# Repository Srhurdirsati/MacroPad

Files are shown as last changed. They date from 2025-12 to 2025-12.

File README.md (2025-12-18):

# MacroPad
This is a small **4-key RGB macro pad** project built using the Seeed Studio XIAO RP2040.  
It is designed as a beginner-friendly hardware + firmware project and can be used as a USB macro pad for shortcuts, media control, or productivity.

---

##  Features

- 4 mechanical keys
- Per-key RGB lighting using SK6812 MINI LEDs
- Rotary encoder for volume / Brightness
- OLED display for status 
- USB HID 
- Compact custom PCB
- Customizable Code For Customized Features

---

## Components Used

### Microcontroller
- **Seeed Studio XIAO RP2040**  
  Link: https://robu.in/product/seeed-studio-xiao-rp2040-v1-0/ $6 With Shipping

### Mechanical Switches
- **Cherry MX 5-pin switches (Silent Red)**  
  Link:  
  https://www.thecosmicbyte.com/product/cherry-mx-mechancial-5-pin-switches-compatible-with-hot-swappable-keyboards-pack-of-10/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 $6 With Shipping 

### Other Parts
- SK6812 RGB LEDs (5 pcs) $1 From My Local Shop 
- Rotary encoder wih switch  $2 from my local shop 
- [0.96" I2C OLED display](https://robu.in/product/0-96-oled-display-module/) - $3 with shipping  
- Custom PCB (JLCPCB – approx **$11 USD** for prototype with shiping )

   GRAND TOTAL = 6+6+1+2+3+11 = 39 => ~$40

---

## How To Use Rorary Encoder 

- Double Click to switch btw brightness and volume
- Scroll to adjust
- Tripple Click To Switch RGB Modes
- Single Click For Play Pause

   CODE CAN BE EDITED AS PER CHOICE   

---

## Images

Schematic

PCB

3D



Top

Top 2

Assembly

Ass 2

## JLC Cart 

JLC CART

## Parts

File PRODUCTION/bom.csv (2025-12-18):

Designator | Footprint | Quantity | Value | LCSC Part #
D1, D2, D3, D4 | LED_SK6812MINI_PLCC4_3.5x3.5mm_P1.75mm | 4 | SK6812MINI
J1 | PinHeader_1x04_P1.00mm_Vertical | 1 | Conn_01x04_MountingPin
SW1, SW2, SW3, SW4 | SW_Cherry_MX_1.00u_PCB | 4 | SW_Push
SW6 | RotaryEncoder_Alps_EC11E-Switch_Vertical_H20mm | 1 | RotaryEncoder_Switch
U1 | XIAO-RP2040-DIP | 1 | XIAO-RP2040-DIP

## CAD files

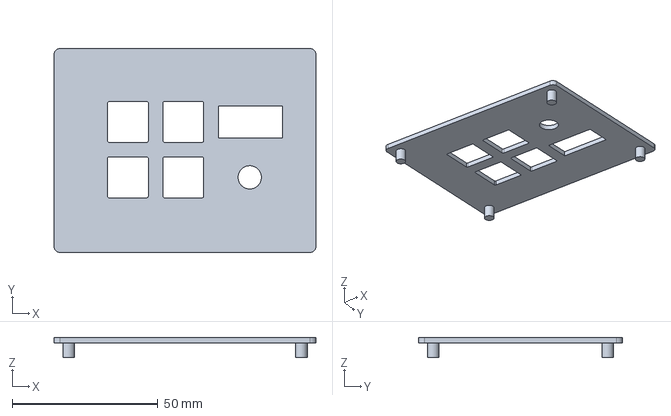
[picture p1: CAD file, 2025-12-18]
CAD/Top Case.FCStd
90.0 x 70.0 x 7.00 mm

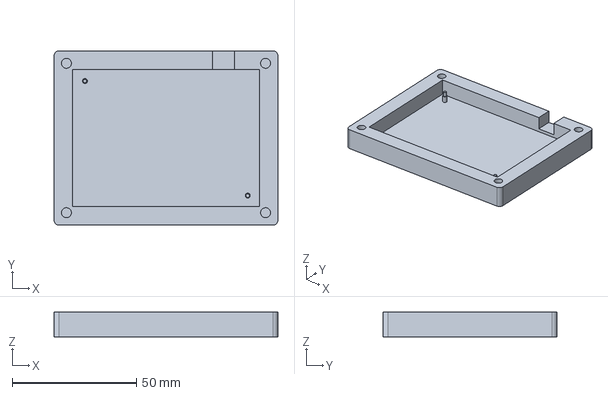
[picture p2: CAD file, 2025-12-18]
CAD/Case Bottom.FCStd
90.0 x 70.0 x 10.0 mm

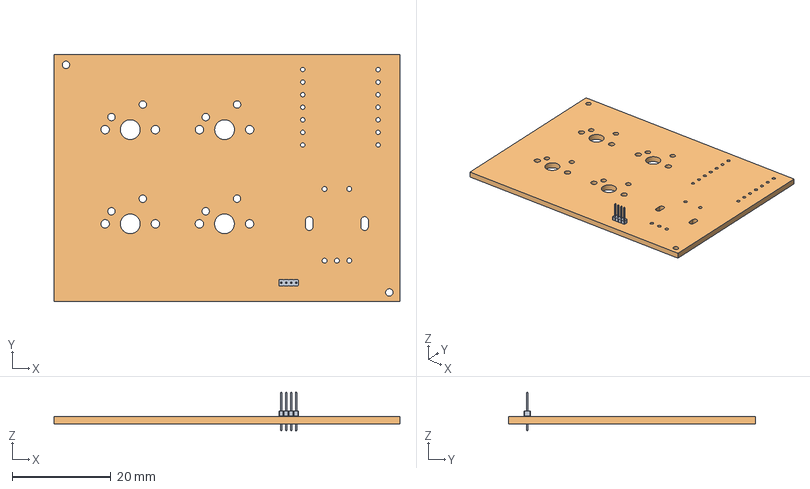
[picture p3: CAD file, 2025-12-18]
CAD/PCB.FCStd
70.0 x 50.0 x 7.80 mm
PinHeader_1x04_P1.00mm_Vertical
Hackpad_PCB

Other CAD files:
CAD/Ass.FCStd

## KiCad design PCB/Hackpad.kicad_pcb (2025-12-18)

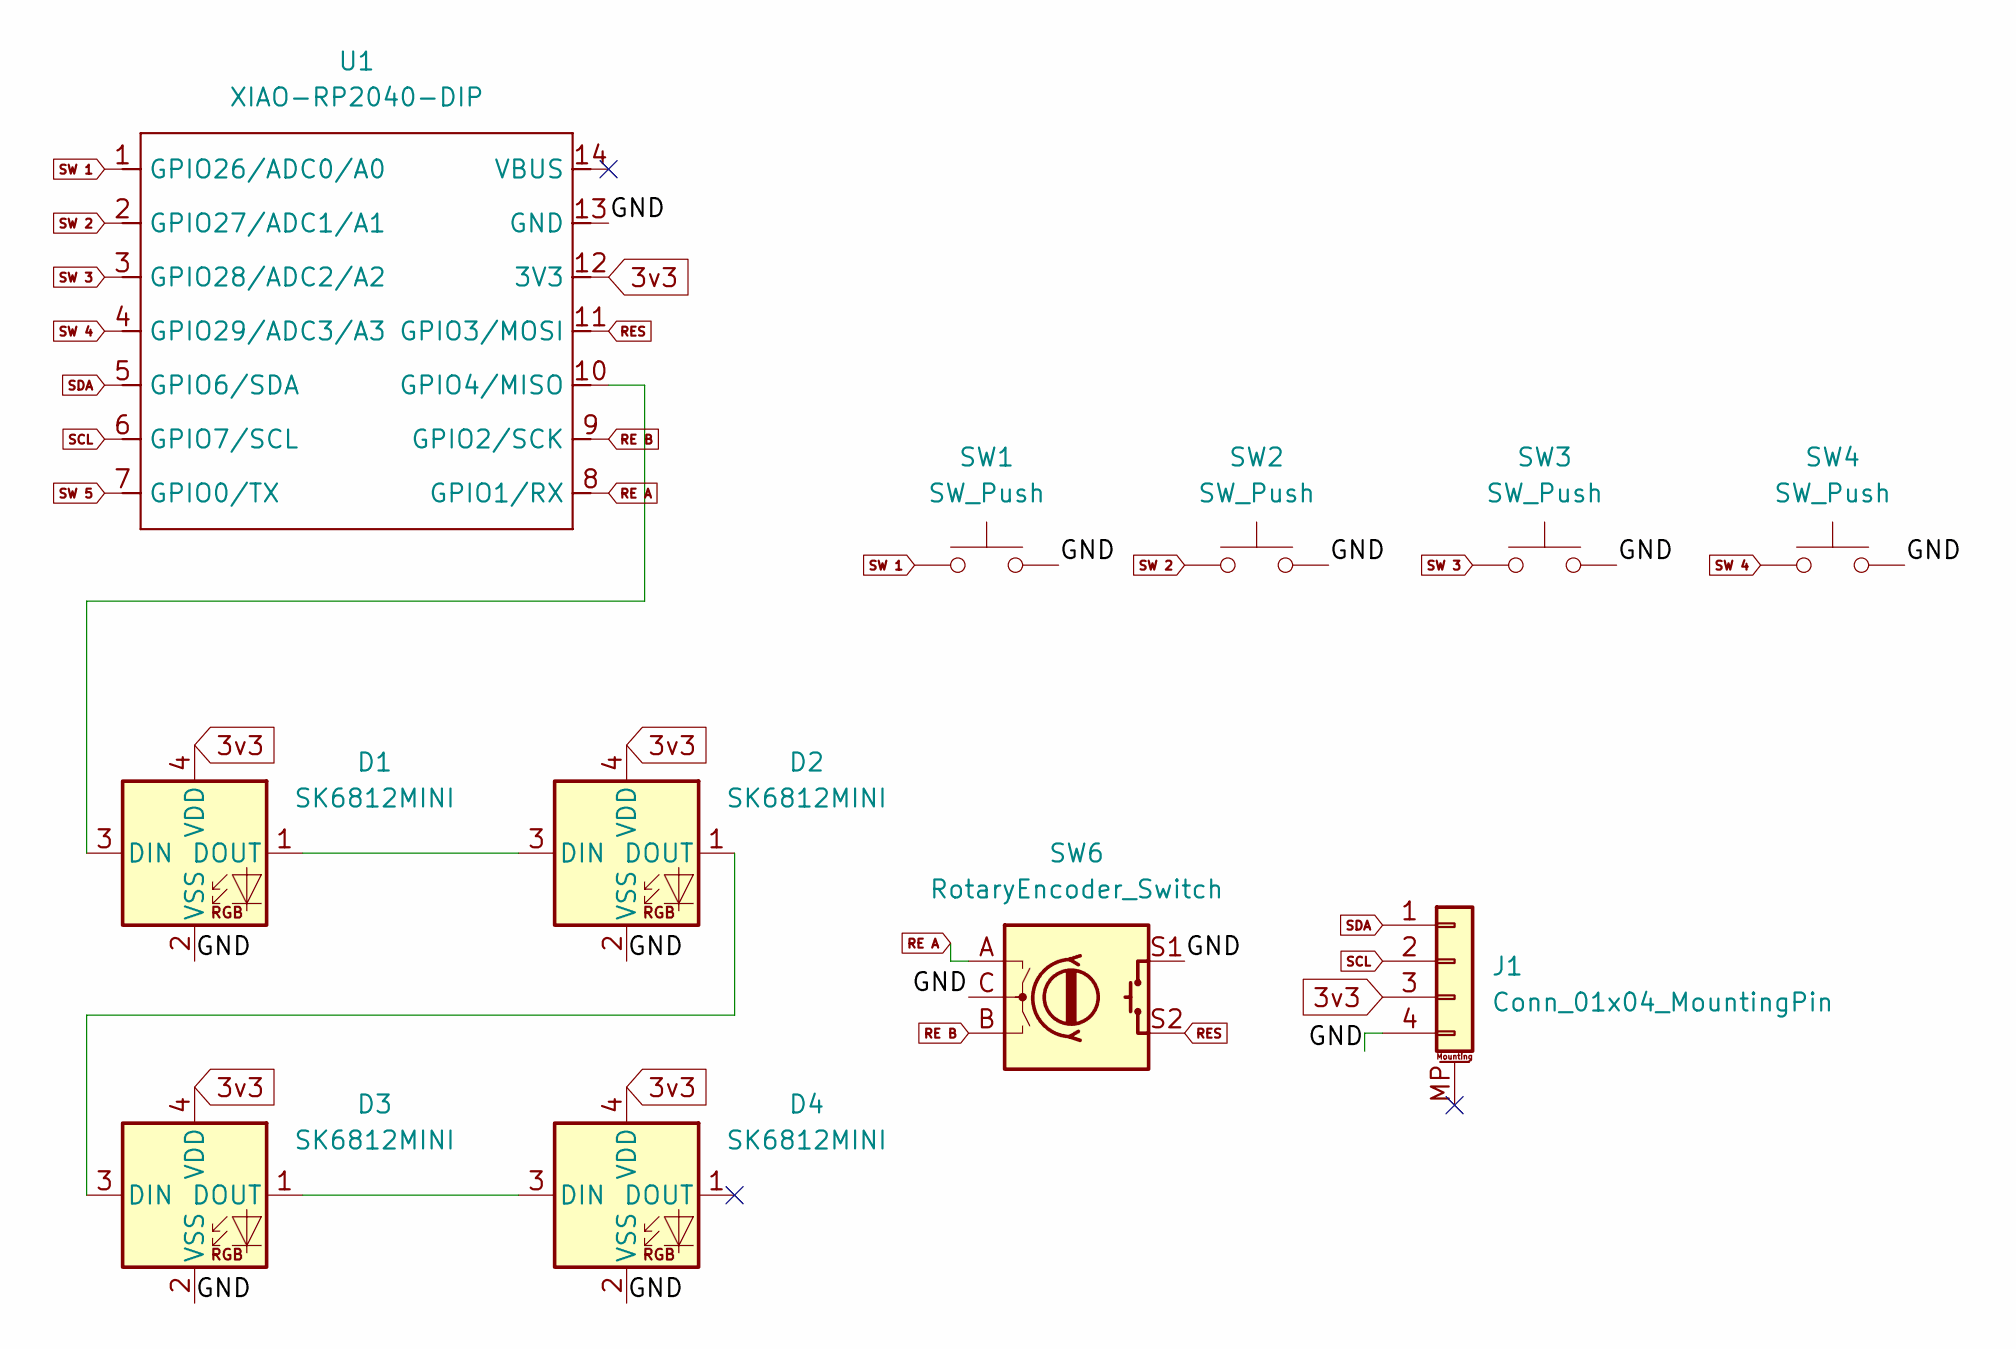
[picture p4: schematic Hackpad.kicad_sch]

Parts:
D1, D2, D3, D4: SK6812MINI; LED_SK6812MINI_PLCC4_3.5x3.5mm_P1.75mm
J1: Conn_01x04_MountingPin; PinHeader_1x04_P1.00mm_Vertical
SW1, SW2, SW3, SW4: SW_Push; SW_Cherry_MX_1.00u_PCB
SW6: RotaryEncoder_Switch; RotaryEncoder_Alps_EC11E-Switch_Vertical_H20mm
U1: XIAO-RP2040-DIP

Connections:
3v3: D1.4 (VDD), D2.4 (VDD), D3.4 (VDD), D4.4 (VDD), J1.3, U1.12 (3V3)
/GND: D1.2 (VSS), D2.2 (VSS), D3.2 (VSS), D4.2 (VSS), J1.4, SW1.2, SW2.2, SW3.2, SW4.2, SW6.C, SW6.S1, U1.13 (GND)
unnamed: D1.3 (DIN), U1.10 (GPIO4/MISO)
unnamed: D1.1 (DOUT), D2.3 (DIN)
unnamed: D2.1 (DOUT), D3.3 (DIN)
unnamed: D3.1 (DOUT), D4.3 (DIN)
RE A: SW6.A, U1.8 (GPIO1/RX)
RE B: SW6.B, U1.9 (GPIO2/SCK)
RES: SW6.S2, U1.11 (GPIO3/MOSI)
SCL: J1.2, U1.6 (GPIO7/SCL)
SDA: J1.1, U1.5 (GPIO6/SDA)
SW 1: SW1.1, U1.1 (GPIO26/ADC0/A0)
SW 2: SW2.1, U1.2 (GPIO27/ADC1/A1)
SW 3: SW3.1, U1.3 (GPIO28/ADC2/A2)
SW 4: SW4.1, U1.4 (GPIO29/ADC3/A3)
SW 5: U1.7 (GPIO0/TX)

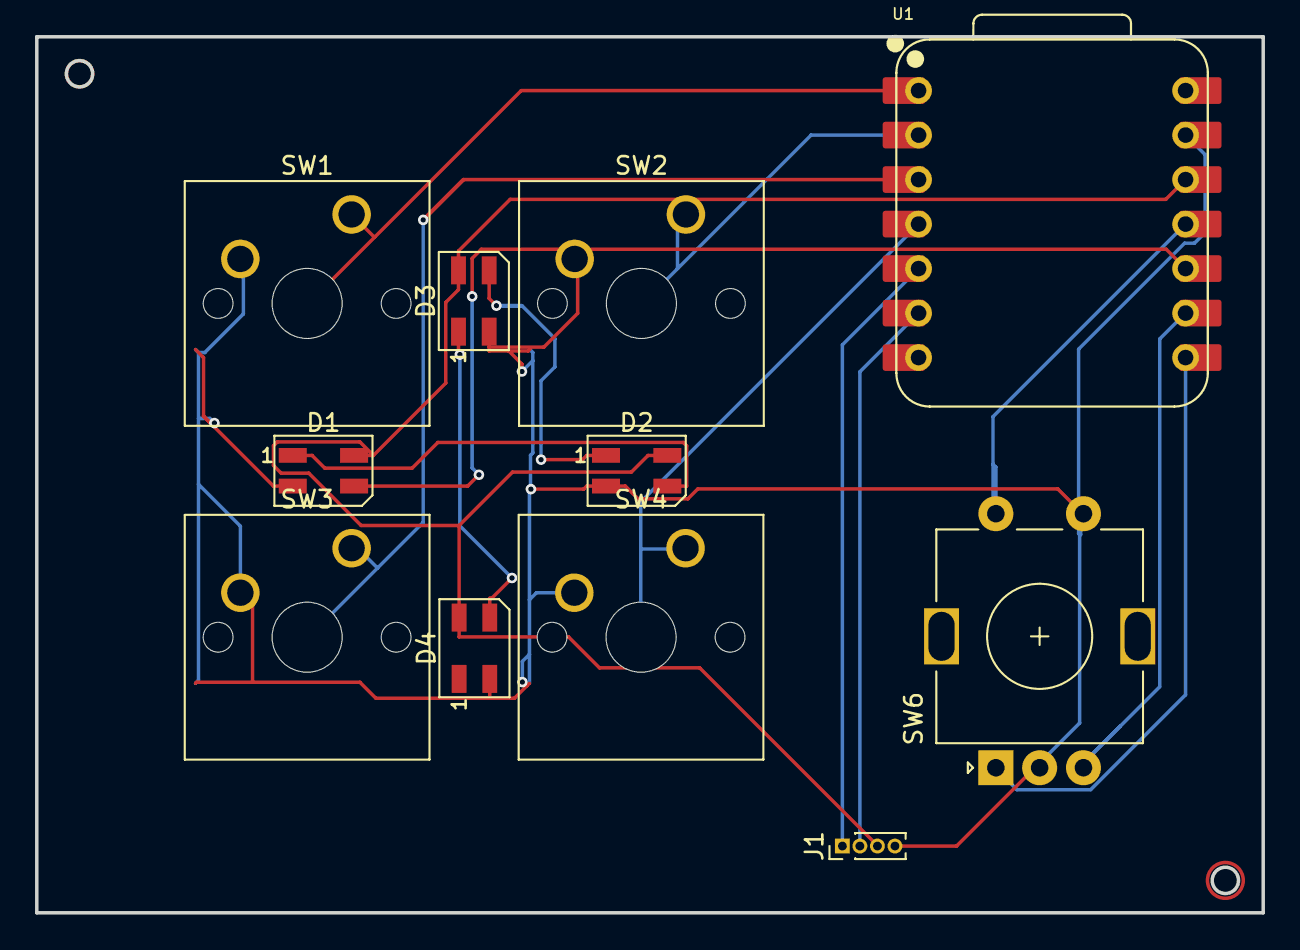
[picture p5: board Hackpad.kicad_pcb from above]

Board: 2 copper layers, 70.0 x 50.0 mm, 11 parts (0 on the bottom side), 15 nets.

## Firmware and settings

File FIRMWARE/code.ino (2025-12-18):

#include <Keyboard.h>
#include <Adafruit_NeoPixel.h>
#include <Wire.h>
#include <Adafruit_GFX.h>
#include <Adafruit_SSD1306.h>
#include <Encoder.h>

#define SW1 26
#define SW2 27
#define SW3 28
#define SW4 29

#define ENC_A 1
#define ENC_B 2
#define ENC_SW 3

#define RGB_PIN 4
#define LED_COUNT 4

#define OLED_SDA 6
#define OLED_SCL 7

Adafruit_NeoPixel leds(LED_COUNT, RGB_PIN, NEO_GRB + NEO_KHZ800);
Encoder encoder(ENC_A, ENC_B);
Adafruit_SSD1306 display(128, 64, &Wire, -1);

long lastPos = 0;
unsigned long lastTapTime = 0;
int tapCount = 0;

bool volumeMode = true;
int rgbMode = 0;
int brightness = 100;

void setRGB() {
  leds.clear();
  if (rgbMode == 0) {
    for (int i = 0; i < LED_COUNT; i++)
      leds.setPixelColor(i, leds.Color(255, 0, 0));
  }
  if (rgbMode == 1) {
    for (int i = 0; i < LED_COUNT; i++)
      leds.setPixelColor(i, leds.Color(0, 255, 0));
  }
  if (rgbMode == 2) {
    for (int i = 0; i < LED_COUNT; i++)
      leds.setPixelColor(i, leds.Color(0, 0, 255));
  }
  leds.setBrightness(brightness);
  leds.show();
}

void updateOLED() {
  display.clearDisplay();
  display.setCursor(0, 0);
  if (volumeMode)
    display.print("Mode: Volume");
  else
    display.print("Mode: Brightness");
  display.setCursor(0, 16);
  display.print("RGB Mode: ");
  display.print(rgbMode + 1);
  display.display();
}

void setup() {
  pinMode(SW1, INPUT_PULLUP);
  pinMode(SW2, INPUT_PULLUP);
  pinMode(SW3, INPUT_PULLUP);
  pinMode(SW4, INPUT_PULLUP);
  pinMode(ENC_SW, INPUT_PULLUP);

  leds.begin();
  leds.setBrightness(brightness);
  leds.show();

  Wire.setSDA(OLED_SDA);
  Wire.setSCL(OLED_SCL);
  Wire.begin();

  display.begin(SSD1306_SWITCHCAPVCC, 0x3C);
  display.setTextSize(1);
  display.setTextColor(SSD1306_WHITE);

  setRGB();
  updateOLED();

  Keyboard.begin();
}

void loop() {
  if (!digitalRead(SW1)) { Keyboard.write('A'); delay(200); }
  if (!digitalRead(SW2)) { Keyboard.write('B'); delay(200); }
  if (!digitalRead(SW3)) { Keyboard.write('C'); delay(200); }
  if (!digitalRead(SW4)) { Keyboard.write('D'); delay(200); }

  long pos = encoder.read() / 4;
  if (pos != lastPos) {
    if (volumeMode) {
      if (pos > lastPos) Keyboard.write(KEY_MEDIA_VOLUME_UP);
      else Keyboard.write(KEY_MEDIA_VOLUME_DOWN);
    } else {
      if (pos > lastPos && brightness < 255) brightness += 10;
      if (pos < lastPos && brightness > 10) brightness -= 10;
      setRGB();
    }
    lastPos = pos;
  }

  if (!digitalRead(ENC_SW)) {
    if (millis() - lastTapTime < 400) tapCount++;
    else tapCount = 1;

    lastTapTime = millis();
    delay(50);

    while (!digitalRead(ENC_SW));
  }

  if (tapCount > 0 && millis() - lastTapTime > 400) {
    if (tapCount == 1) {
      Keyboard.write(KEY_MEDIA_PLAY_PAUSE);
    }
    if (tapCount == 2) {
      volumeMode = !volumeMode;
      updateOLED();
    }
    if (tapCount == 3) {
      rgbMode++;
      if (rgbMode > 2) rgbMode = 0;
      setRGB();
      updateOLED();
    }
    tapCount = 0;
  }
}
